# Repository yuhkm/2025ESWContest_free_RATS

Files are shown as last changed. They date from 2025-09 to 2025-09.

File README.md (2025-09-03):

# 2025ESWContest_free_RATS
<br/>

## Driving Assistance Device for Beginner Drivers

<p align="center">
 
</p>
<br/>

## System Overview
<p align="center">
 
</p>
<br/>

## Team Members
<div align="center">

| **안재원 (팀장)** | **김유환** | **박요한** | **박수현** | **정연홍** |
|:---:|:---:|:---:|:---:|:---:|
|  |  |  |  |  |
| [@JwAhn0830](https://github.com/JwAhn0830) | [@yuhkm](https://github.com/yuhkm) | [@doct-vg](https://github.com/doct-vg) | [@jstrfunctionk](https://github.com/strfunctionk) | [@zyh3569](https://github.com/zyh3569) |
| [Main Device (Gaze),](https://github.com/yuhkm/2025ESWContest_free_RATS/tree/main/Main_Device/gaze)<br/>[Server Communication](https://github.com/yuhkm/2025ESWContest_free_RATS/tree/main/Main_Device) | [Main Device (Lane),](https://github.com/yuhkm/2025ESWContest_free_RATS/tree/main/Main_Device/LDS)<br/>[HUD](https://github.com/yuhkm/2025ESWContest_free_RATS/tree/main/HUD) | [Vehicle Sensors,](https://github.com/yuhkm/2025ESWContest_free_RATS/tree/main/Main_Device/VDP)<br/>[CAD](https://github.com/yuhkm/2025ESWContest_free_RATS/tree/main/HW) | [Backend](https://github.com/yuhkm/2025ESWContest_free_RATS/tree/main/Backend) | [Frontend](https://github.com/yuhkm/2025ESWContest_free_RATS/tree/main/Frontend) |

</div>
<br/>

## Demo
- [YouTube](https://www.youtube.com/watch?v=WTc7l_RPrZw)  
<br/>

## Repo
- [Main Device](https://github.com/yuhkm/2025ESWContest_free_RATS/tree/main/Main_Device)  
- [HUD](https://github.com/yuhkm/2025ESWContest_free_RATS/tree/main/HUD)
- [Backend](https://github.com/yuhkm/2025ESWContest_free_RATS/tree/main/Backend)  
- [Frontend](https://github.com/yuhkm/2025ESWContest_free_RATS/tree/main/Frontend)  
- [HW](https://github.com/yuhkm/2025ESWContest_free_RATS/tree/main/HW)
<br/>

<br/>

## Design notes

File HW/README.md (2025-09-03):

# HW
- CAD
  - SolidWorks
- PCB
  - KiCAD  

<br>

## CAD

### Raspberry Pi 5 case  
  

### HUD case  
  

### Camera case  
  

### IMU case  
  

<br>
<br>

## PCB



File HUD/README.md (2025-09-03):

# HUD
<br>

This project receives **lane deviation** and **inter-vehicle distance** data from a Raspberry Pi, displays the information on an ESP32-based display module, and implements a **HUD** (Head-Up Display) using a combiner method.

<p align="center">
  
  
</p>

### Key Features
- Real-time visualization of lane deviation and following distance  
- Display output using ESP32 and LVGL  
- HUD implementation via combiner reflection  
- Touch-based UI with calibration functionality

<br>

## HW
- Waveshare ESP32-S3 2.41inch AMOLED Touch Display
  - MCU : ESP32-S3
  - Driver IC : RM690B0
  - Touch IC : FT6336

<br>

## SW
- **Squareline Studio** : 1.5.3
- **LVGL** : 8.3.11
- **IDE** : PlatformIO

<br>

## System Overview
<p align="center">
  
</p>
<br>

## HUD usage example

<table align="center">
  <tr>
    <td align="center">
      Offset calibration<br>
      <strong>Offset calibration mode</strong><br>
      <strong>&nbsp;</strong>
    </td>
    <td align="center">
      Left deviation<br>
      <strong>Center driving</strong><br>
      <strong>Safe distance</strong>
    </td>
  </tr>
  <tr>
    <td align="center">
      Normal driving<br>
      <strong>Left bias</strong><br>
      <strong>Warning distance</strong>
    </td>
    <td align="center">
      Normal driving<br>
      <strong>Right bias</strong><br>
      <strong>Dangerous distance</strong>
    </td>
  </tr>
</table>

<br>

## Project structure

```markdown
HUD
┣ HUD
┃ ┗ lib
┃ ┃ ┗ UI
┃ ┃   ┗ ...
┃ ┗ src
┃ ┃ ┣ esp_lcd_sh8601.c
┃ ┃ ┣ esp_lcd_sh8601.h
┃ ┃ ┣ esp_lcd_touch.c
┃ ┃ ┣ esp_lcd_touch.h
┃ ┃ ┣ esp_lcd_touch_ft5x06.c
┃ ┃ ┣ esp_lcd_touch_ft5x06.h
┃ ┃ ┣ hudCtrl.cpp
┃ ┃ ┣ hudCtrl.h
┃ ┃ ┗ main.cpp
┃ ┗ platformio.ini
┃
┣ libraries
┃ ┗ ESP32-audioI2S-master
┃ ┗ lvgl
┃ ┗ lv_conf.h
┃
┣ HUD_amoled_v1
┃ ┗ ...
┃
┗ README.md
```

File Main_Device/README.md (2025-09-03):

<p align="center">
   
</p>

# Dev Environemnt 
## Host Environment 
### Build PC 
- **CPU** : Intel i7 13th
- **GPU** : NVIDIA RTX 4050
- **RAM** : 32GB
- **OS** : Ubuntu-22.04 LTS (WSL2)
- **Target Hailo NPU** : Hailo8  

### Hailo SDK
- **Hailo Model Zoo** : 2.15v
- **DataFlow Compiler** : 3.31v
- **Hailort** : 4.21v
- **Python venv** : 3.10.2

## Target Environemnt
### HW
- **Target Board** : RasberryPI 5
- **NPU** : Hailo 8

### SW
- **Python** : 3.11.4
- **HailoRT** : 4.20v  

# System Overview
<p align="center">
 
</p>

- **MultiProcessor**
    - To enhance system efficiency and prevent resource bottlenecks, the application uses multiprocessing. Independent processes are assigned to handle gaze tracking (app.py) and lane detection with distance estimation (lds.py), enabling parallel execution of compute-intensive tasks.

- **MultiThread**
    - Multithreading is used for handling GPS and IMU data concurrently. GPS data is used to measure driving distance and speed, while IMU data helps determine the vehicle’s turn signal status (e.g., left or right turn). This approach improves responsiveness and stability of the system.

- **WebScoket**
  - the device and server are connected via a TCP-based websocket communication protocol.

- **Hailo NPU**
    - Since the Raspberry Pi lacks a dedicated GPU, the system utilizes the Hailo NPU for efficient and real-time AI model inference on edge device

- **Used  library**
    - *OpenCV* : For lane detection
    - *Mediapipe* : For estimating user's face angle 

- [HUD](https://github.com/Driving-Assistance-Device/HUD)
    - Lane deviation and inter-vehicle distance data are received from a Raspberry Pi and displayed on an ESP32 module. A combiner-type HUD then projects the information into the driver’s line of sight.

# multi-proess


- [main.py](https://github.com/Driving-Assistance-Device/Vehicle_Device/tree/main/DM)
    - Main process
    
- [lds.py](https://github.com/Driving-Assistance-Device/Vehicle_Device/tree/main/DM/LDS)
    - Lane & inter-vehicle distance detection system
- [gaze.py](https://github.com/Driving-Assistance-Device/Vehicle_Device/tree/main/DM/gaze)  
    - Gaze detection system

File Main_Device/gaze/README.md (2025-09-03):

## gaze.py



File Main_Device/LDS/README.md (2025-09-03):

## LDS.py


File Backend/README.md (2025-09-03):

<div align=center>
  
# Vehicle-BackEnd
초보 운전자를 위한 차량 보조 서비스 벡엔드 레포지토리 입니다.

## 인원

|  |
| :-----------------------------------------------------------------------------: |
|                    [박수현](https://github.com/strfunctionk)                    |

## 기술 스택

| 이름 | 소개 |
| --- | --- |
|  | \* 서버 사이드 JavaScript 환경입니다. |
|  | \* Node.js를 위한 웹 애플리케이션 프레임워크입니다. |
|  | \* 실시간 통신을 위한 웹소켓 라이브러리입니다. |
|  | _ EC2: 가상 서버 인스턴스를 제공하는 AWS 서비스입니다. <br> _ S3: 객체 스토리지 서비스입니다. <br> \* RDS: 관리형 관계형 데이터베이스 서비스입니다. |
|  | \* 관계형 데이터베이스 서비스입니다. |
|  | \* ORM(Object-Relational Mapping) 라이브러리입니다. |

</div>

## 개요

- 명칭 : Vehicle
- 개발인원 : 1명 (박수현)
- 개발기간 : 2025.06.24 ~ ing
- 브랜치전략 : GitHub-Flow

## 코딩 컨벤션

- **변수, 함수:** 카멜케이스 (예: `userName`)
- **매개변수:** 스네이크케이스 (예: `user_name`)

## Commit

- `feature` : 새로운 기능이 추가되는 경우
- `fix` : bug가 수정되는 경우
- `docs` : 문서에 변경 사항이 있는 경우
- `refactor` : 코드 리팩토링하는 경우 (기능 변경 없이 구조 개선)

## PR 템플릿

```markdown
#️⃣연관된 이슈

ex) #이슈번호, #이슈번호

📝작업 내용
이번 PR에서 작업한 내용을 간략히 설명해주세요(이미지 첨부 가능)

스크린샷 (선택)

💬리뷰 요구사항(선택)
```

## 프로젝트 구조

```markdown
📦 project/
┃ 📂prisma/
┃ ┗ 📜schema.prisma
┣ 📂src/
┃ ┣ 📂routes/
┃ ┃ ┗ 📜index.js
┃ ┃ ┗ 📜auth.services.js
┃ ┃ ┗ 📜driving.services.js
┃ ┃ ┗ 📜user.services.js
┃ ┣ 📂controllers/
┃ ┃ ┗ 📜auth.controller.js
┃ ┃ ┗ 📜driving.controller.js
┃ ┃ ┗ 📜user.controller.js
┃ ┣ 📂dtos/
┃ ┃ ┗ 📜auth.dto.js
┃ ┃ ┗ 📜device.dto.js
┃ ┃ ┗ 📜driving.dto.js
┃ ┃ ┗ 📜user.dto.js
┃ ┣ 📂services/
┃ ┃ ┗ 📜auth.services.js
┃ ┃ ┗ 📜device.services.js
┃ ┃ ┗ 📜driving.services.js
┃ ┃ ┗ 📜user.services.js
┃ ┣ 📂repositories/
┃ ┃ ┗ 📜auth.repository.js
┃ ┃ ┗ 📜device.repository.js
┃ ┃ ┗ 📜driving.repository.js
┃ ┃ ┗ 📜user.repository.js
┃ ┣ 📂middlewares/
┃ ┃ ┗ 📜auth.middleware.js
┃ ┣ 📂utils/
┃ ┃ ┗ 📜crypto.util.js
┃ ┃ ┗ 📜jwt.util.js
┃ ┣ 📂errors/
┃ ┃ ┣ 📜auth.errors.js
┃ ┃ ┣ 📜device.errors.js
┃ ┃ ┣ 📜driving.errors.js
┃ ┃ ┣ 📜user.errors.js
┃ ┣ 📂db/
┃ ┃ ┣ 📜db.config.js
┃ ┗ 📜index.js
┃ 📂test/
┃ ┗ 📜socket.test.js
┣ 📜.env
┗ 📜README.md
```

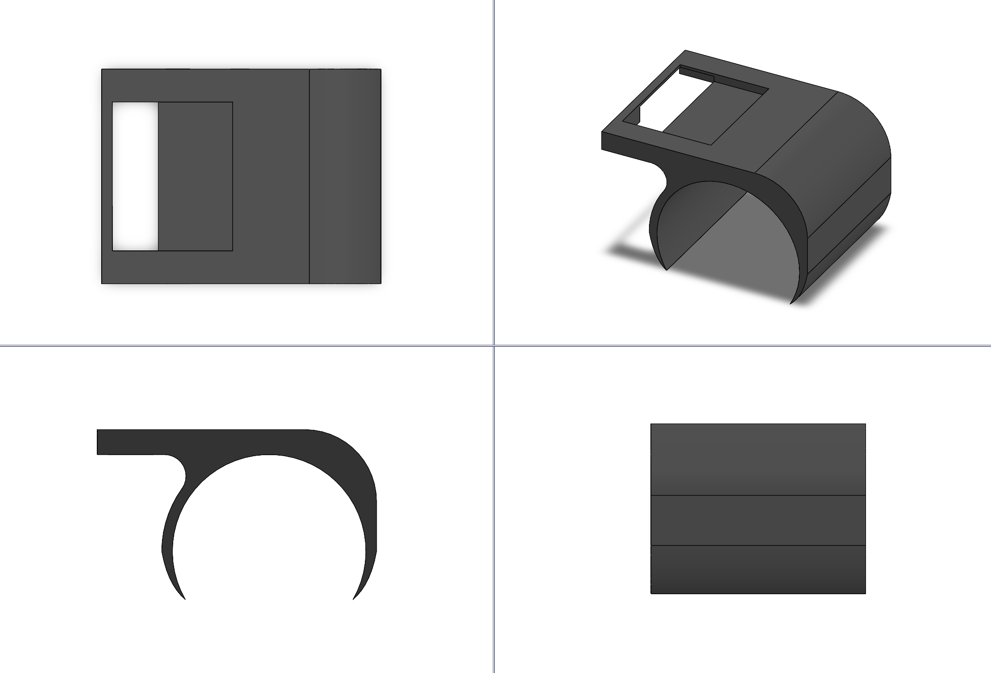
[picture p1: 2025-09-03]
HW/cad/IMU/IMU_case_img.png

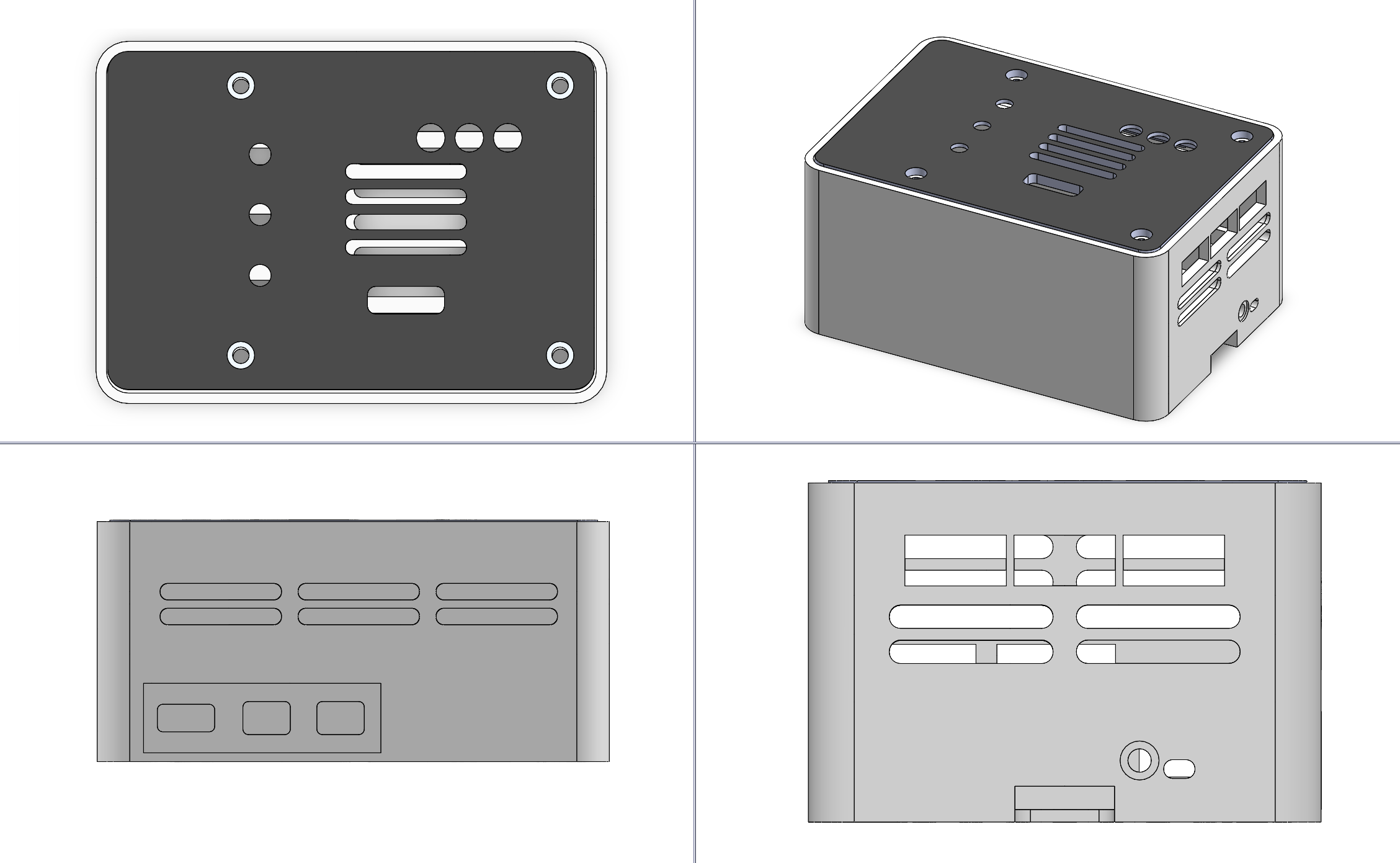
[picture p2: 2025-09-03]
HW/cad/Raspberry Pi5/RP5_case_img.png

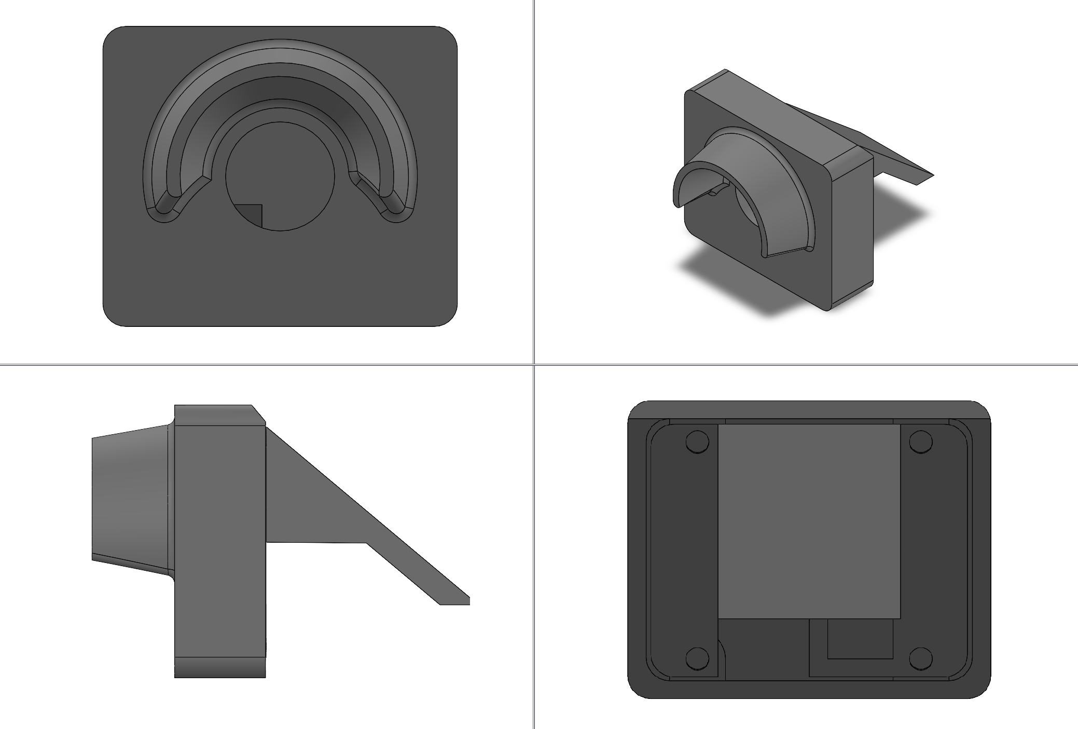
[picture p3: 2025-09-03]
HW/cad/Cam/cam_case_img.png

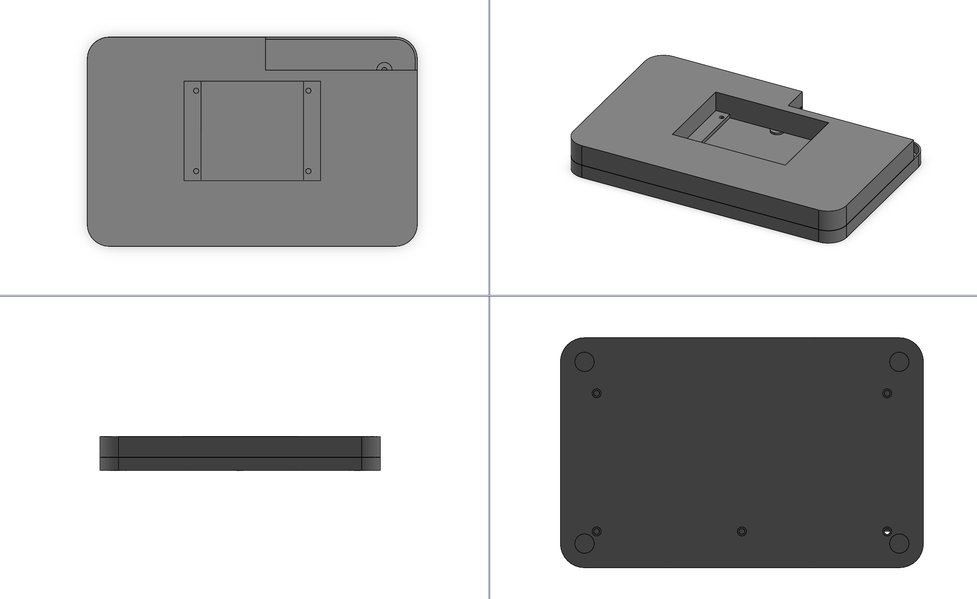
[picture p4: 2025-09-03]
HW/cad/HUD/HUD_case_img.png

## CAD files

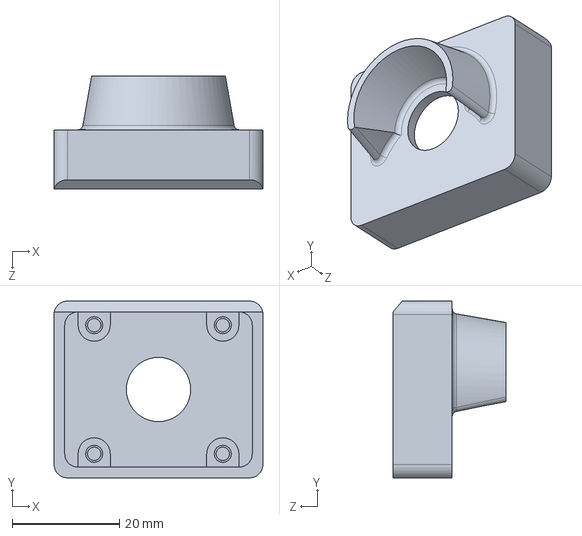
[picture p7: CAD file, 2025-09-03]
HW/cad/Cam/camCase_t.SLDPRT
39.0 x 33.0 x 21.0 mm

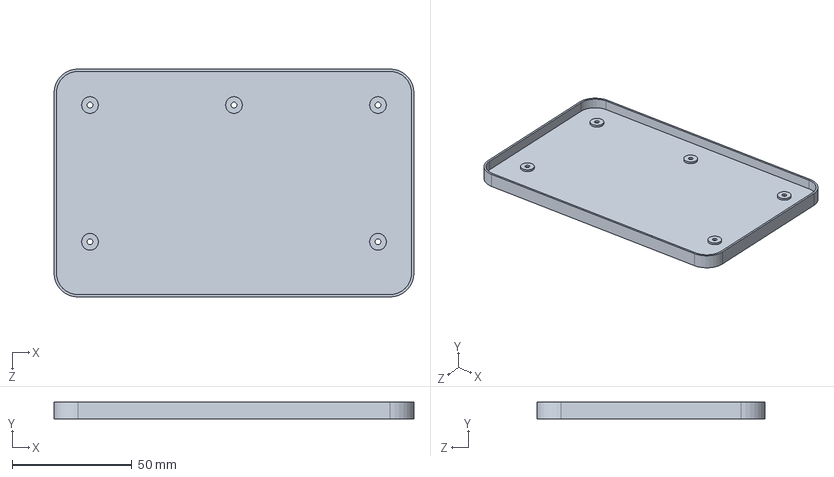
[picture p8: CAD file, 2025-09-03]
HW/cad/HUD/hud_btm.SLDPRT
150.0 x 7.00 x 95.0 mm

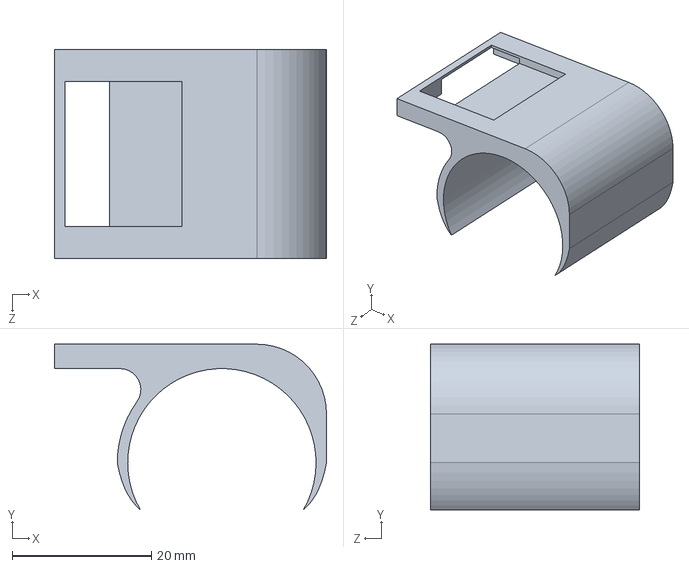
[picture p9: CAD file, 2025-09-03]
HW/cad/IMU/IMU_case.SLDPRT
39.0 x 23.8 x 30.0 mm

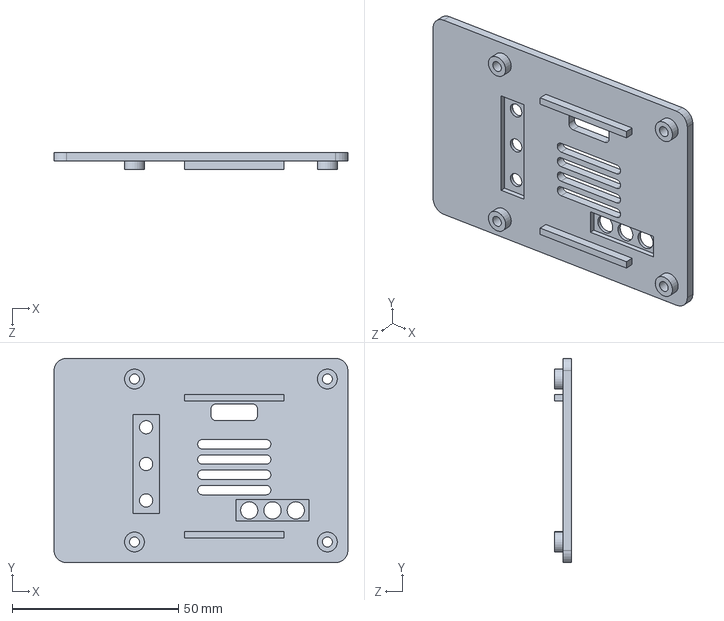
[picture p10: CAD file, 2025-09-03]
HW/cad/Raspberry Pi5/pi5_top.SLDPRT
88.4 x 61.4 x 5.00 mm

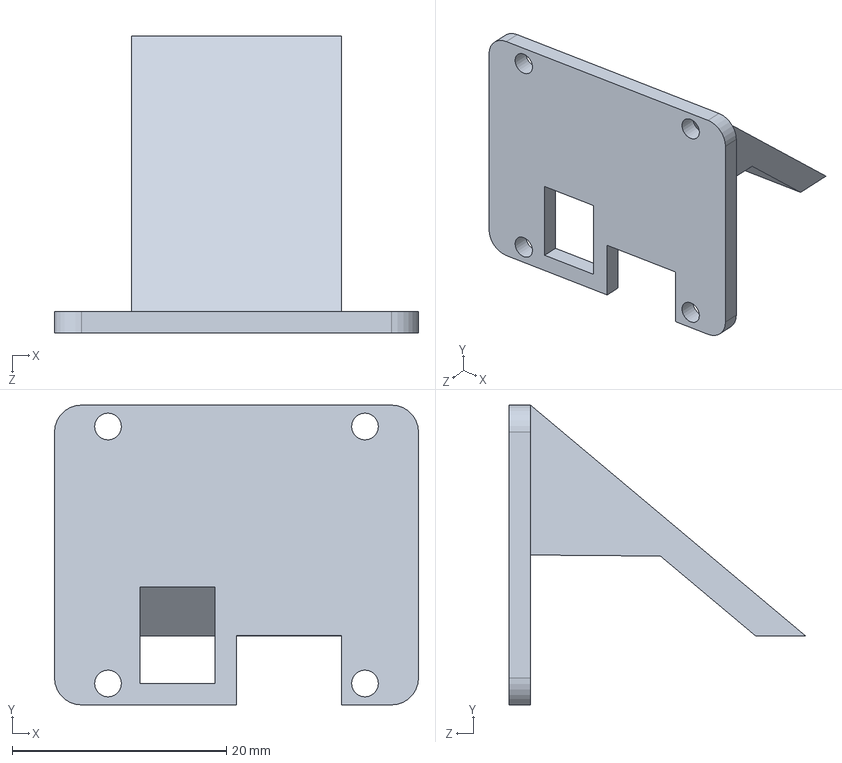
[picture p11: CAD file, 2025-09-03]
HW/cad/Cam/camCase_b.SLDPRT
34.0 x 28.0 x 27.7 mm

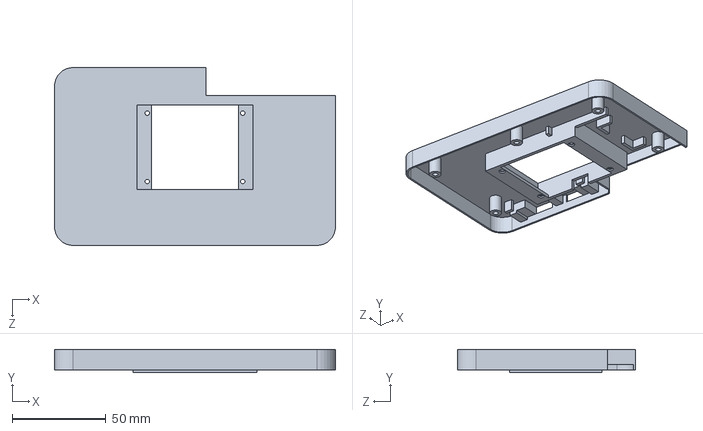
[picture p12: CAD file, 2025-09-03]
HW/cad/HUD/hud_top.SLDPRT
150.0 x 12.5 x 95.0 mm

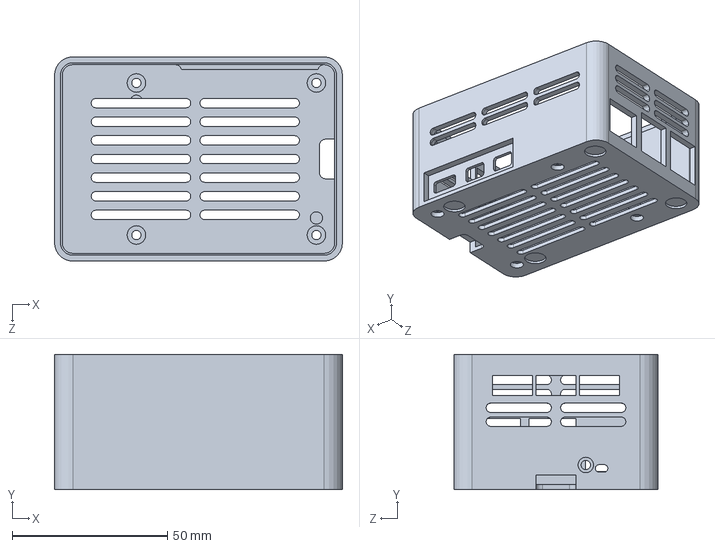
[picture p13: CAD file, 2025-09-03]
HW/cad/Raspberry Pi5/pi5_case.SLDPRT
92.8 x 43.5 x 65.8 mm

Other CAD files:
HW/cad/Cam/camCase_b.STL
HW/cad/Cam/camCase_t.STL
HW/cad/HUD/hud_btm.STL
HW/cad/HUD/hud_top.STL
HW/cad/IMU/IMU_case.STL
HW/cad/Raspberry Pi5/pi5_case.STL
HW/cad/Raspberry Pi5/pi5_top.STL

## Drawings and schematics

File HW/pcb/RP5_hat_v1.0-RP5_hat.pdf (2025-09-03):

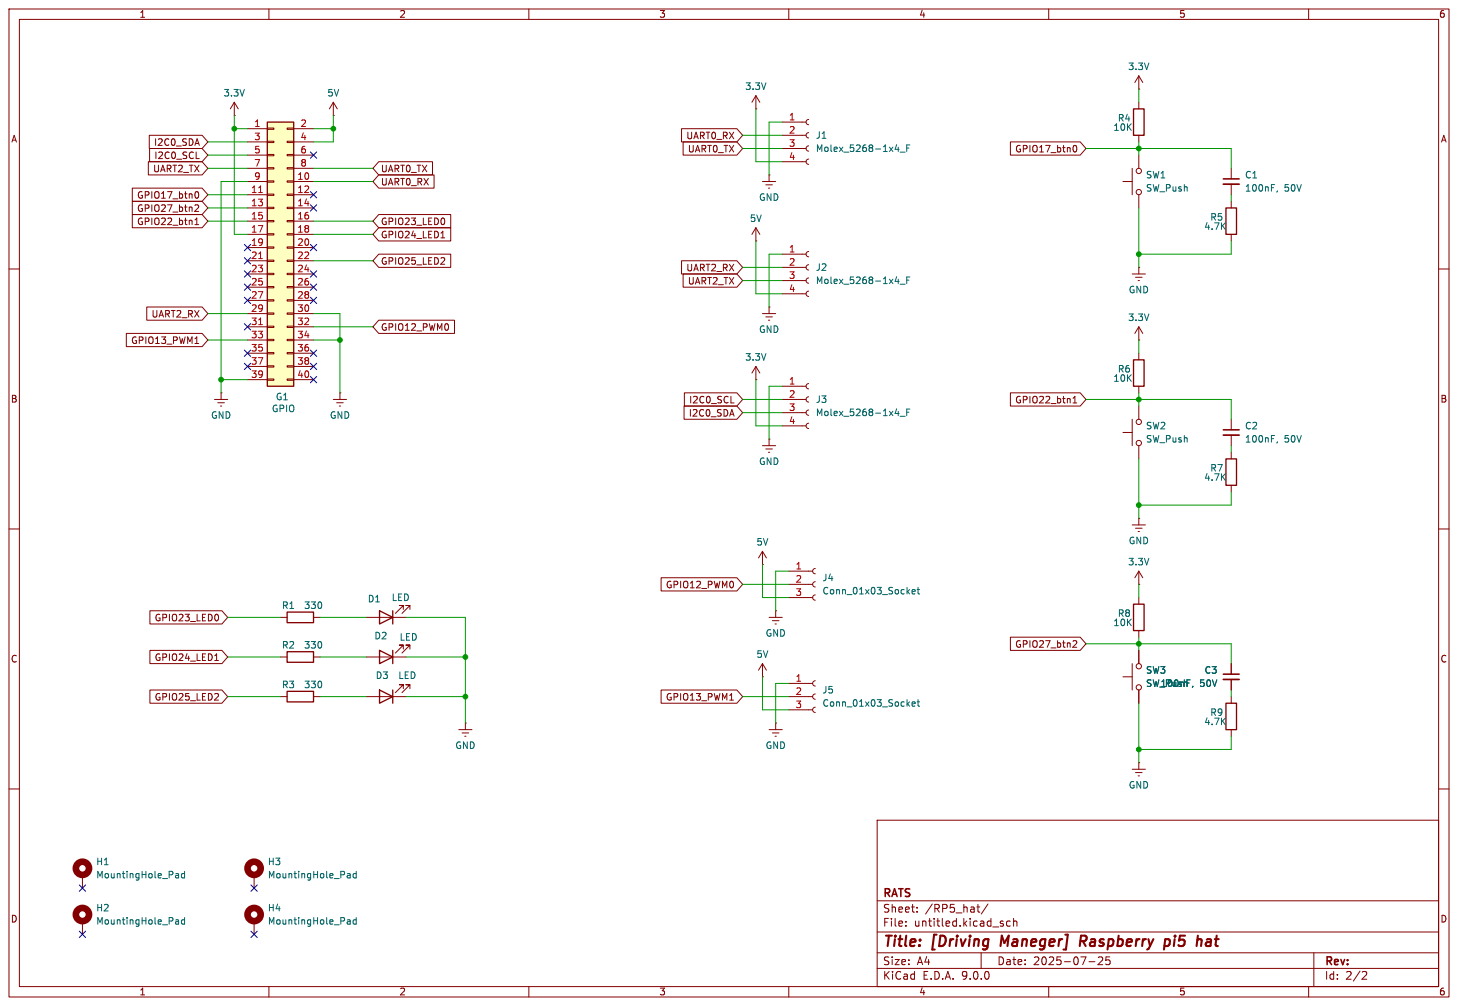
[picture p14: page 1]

Id: 2/2 Title: [Driving Maneger] Raspberry pi5 hat File: untitled.kicad_sch Sheet: /RP5_hat/ RATS

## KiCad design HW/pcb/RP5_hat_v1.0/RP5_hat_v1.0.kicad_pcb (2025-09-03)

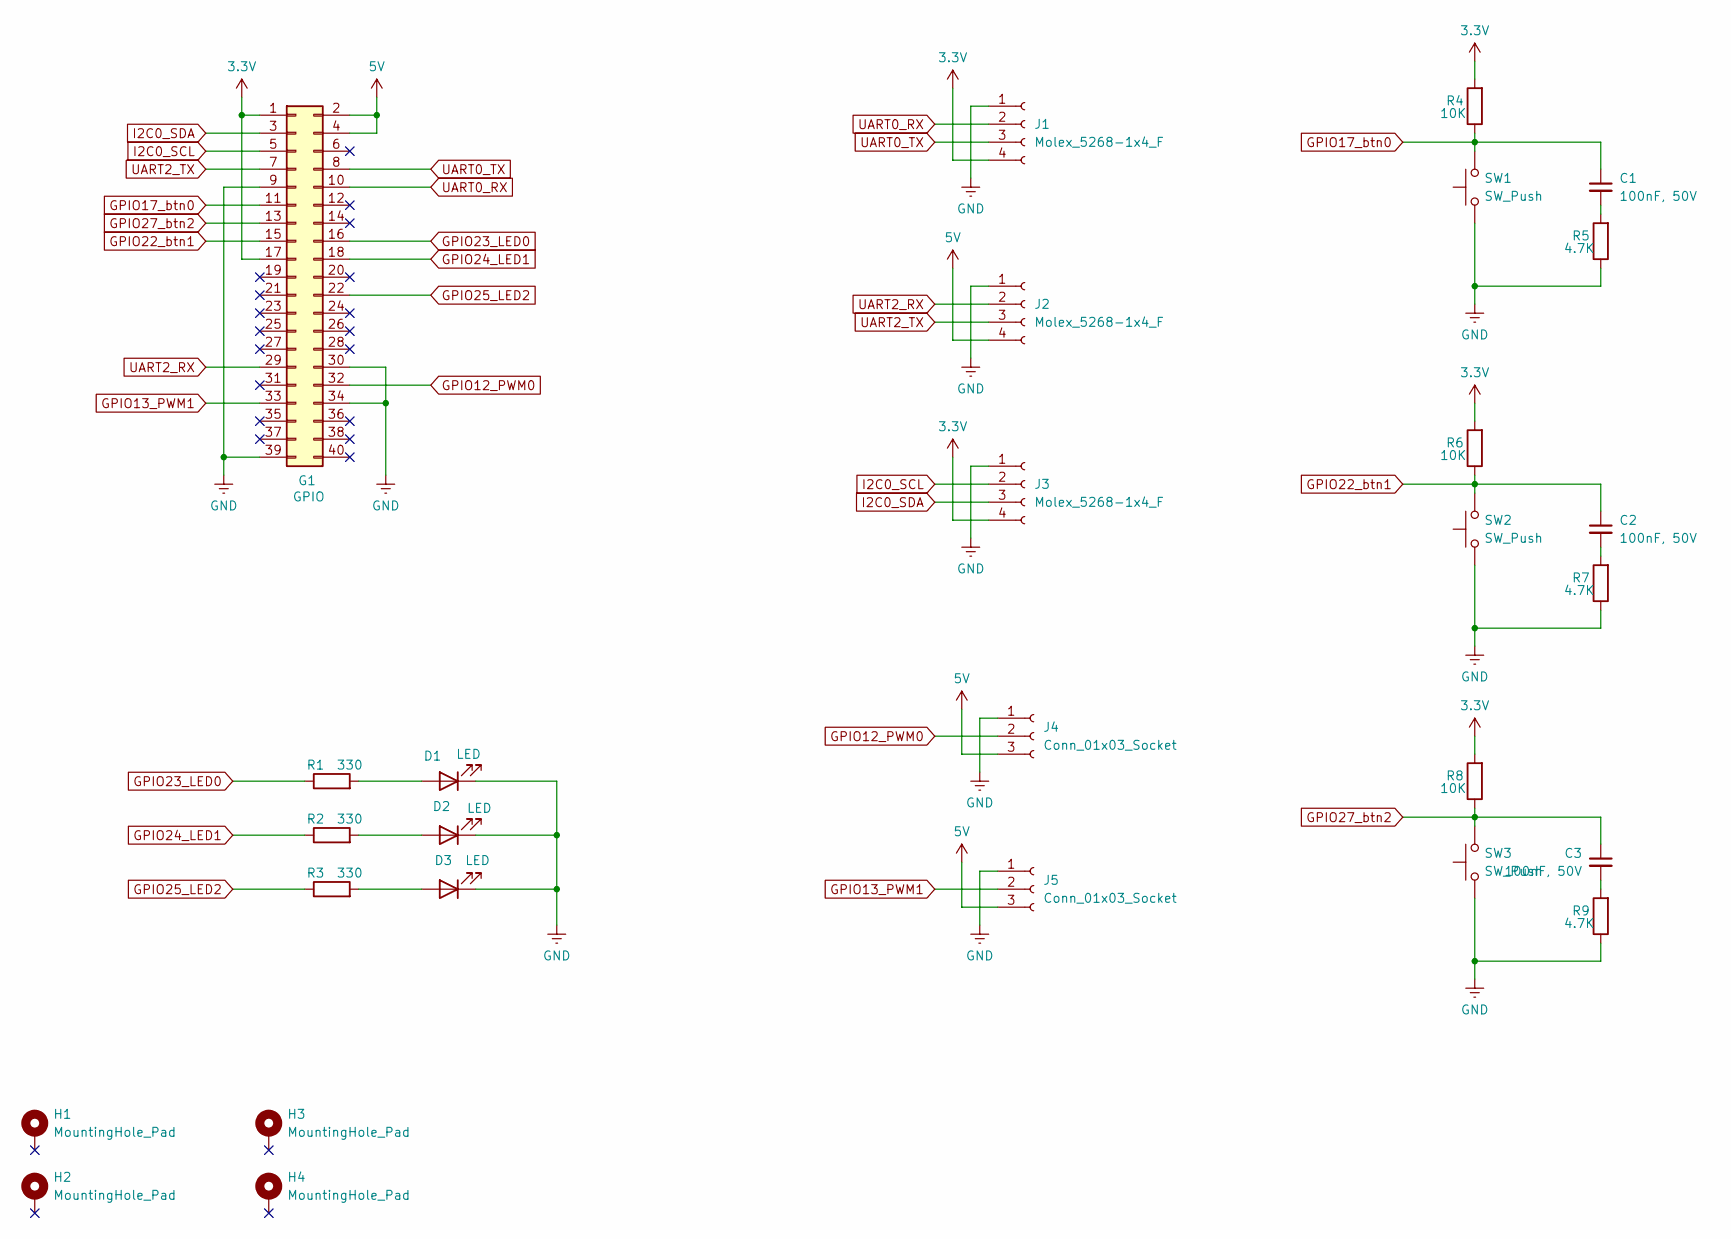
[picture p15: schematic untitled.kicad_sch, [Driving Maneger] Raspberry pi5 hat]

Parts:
C1, C2, C3: 100nF, 50V; CP_Radial_D5.0mm_P2.50mm
D1, D2, D3: LED; LED_D3.0mm
G1: GPIO; PinHeader_2x20_P2.54mm_Vertical
H1, H2, H3, H4: MountingHole_Pad; MountingHole_2.7mm_M2.5_DIN965_Pad_TopBottom
J1, J2, J3: Molex_5268-1x4_F; Molex_SPOX_5267-04A_1x04_P2.50mm_Vertical
J4, J5: Conn_01x03_Socket; Molex_SPOX_5267-03A_1x03_P2.50mm_Vertical
R1, R2, R3: 330; R_Axial_DIN0204_L3.6mm_D1.6mm_P7.62mm_Horizontal
R4, R6, R8: 10K; R_Axial_DIN0204_L3.6mm_D1.6mm_P7.62mm_Horizontal
R5, R7, R9: 4.7K; R_Axial_DIN0204_L3.6mm_D1.6mm_P7.62mm_Horizontal
SW1, SW2, SW3: SW_Push; SW_PUSH_6mm

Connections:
3.3V: G1.1, G1.17, J1.4, J3.4, R4.2, R6.2, R8.2
5V: G1.2, G1.4, J2.4, J4.3, J5.3
GND: D1.1 (K), D2.1 (K), D3.1 (K), G1.9, G1.30, G1.34, G1.39, J1.1, J2.1, J3.1, J4.1, J5.1, R5.1, R7.1, R9.1, SW1.1, SW2.1, SW3.1
GPIO12_PWM0: G1.32, J4.2
GPIO13_PWM1: G1.33, J5.2
GPIO17_btn0: C1.1, G1.11, R4.1, SW1.2
GPIO22_btn1: C2.1, G1.15, R6.1, SW2.2
GPIO23_LED0: G1.16, R1.1
GPIO24_LED1: G1.18, R2.1
GPIO25_LED2: G1.22, R3.1
GPIO27_btn2: C3.1, G1.13, R8.1, SW3.2
I2C0_SCL: G1.5, J3.2
I2C0_SDA: G1.3, J3.3
unnamed: C1.2, R5.2
unnamed: C2.2, R7.2
unnamed: C3.2, R9.2
unnamed: D1.2 (A), R1.2
unnamed: D2.2 (A), R2.2
unnamed: D3.2 (A), R3.2
UART0_RX: G1.10, J1.2
UART0_TX: G1.8, J1.3
UART2_RX: G1.29, J2.2
UART2_TX: G1.7, J2.3

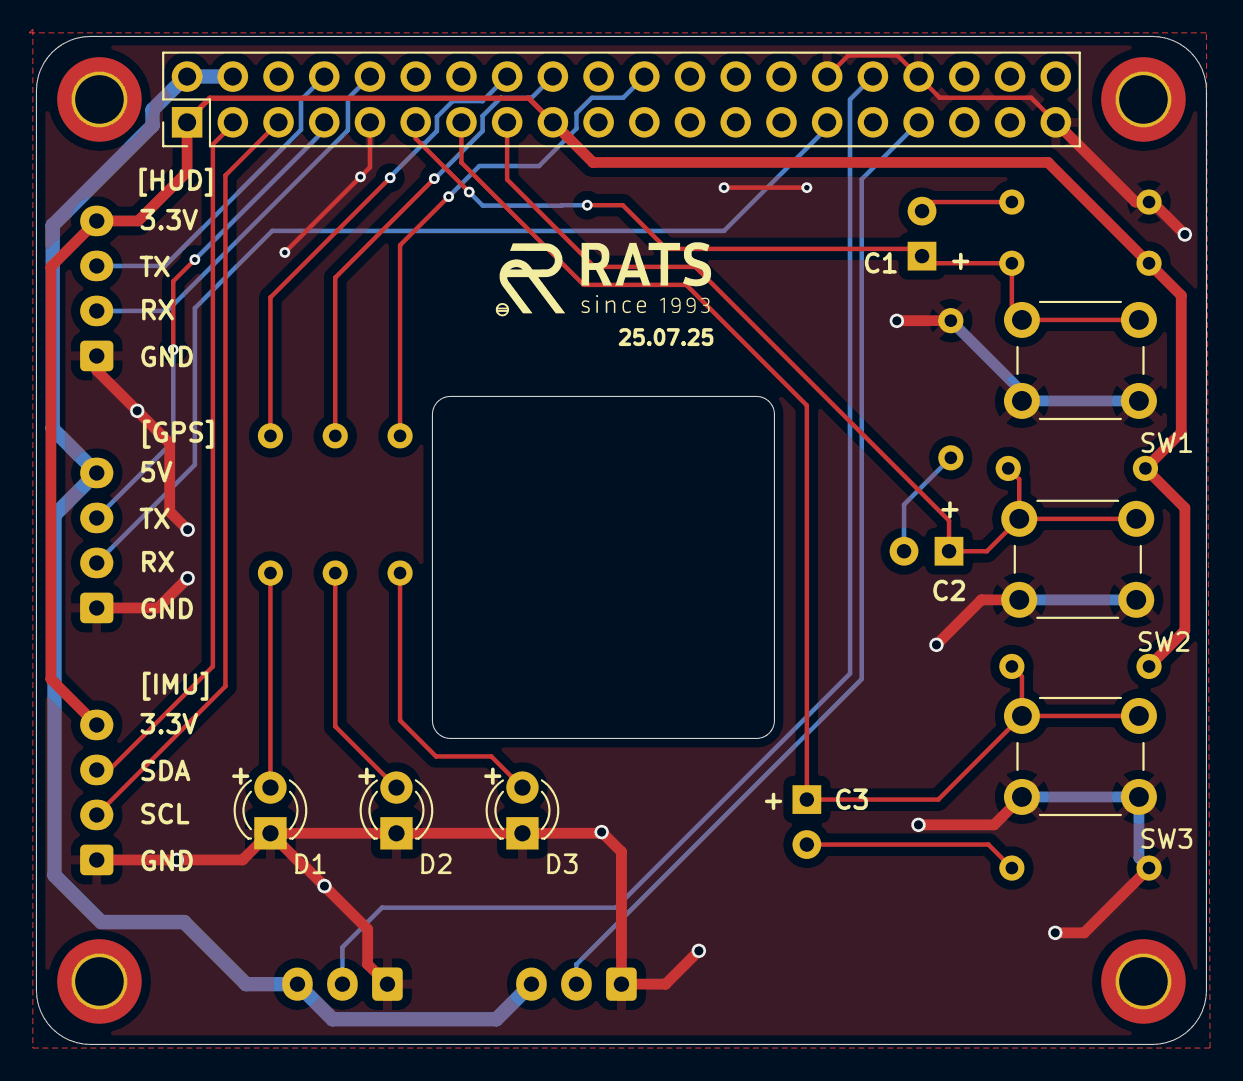
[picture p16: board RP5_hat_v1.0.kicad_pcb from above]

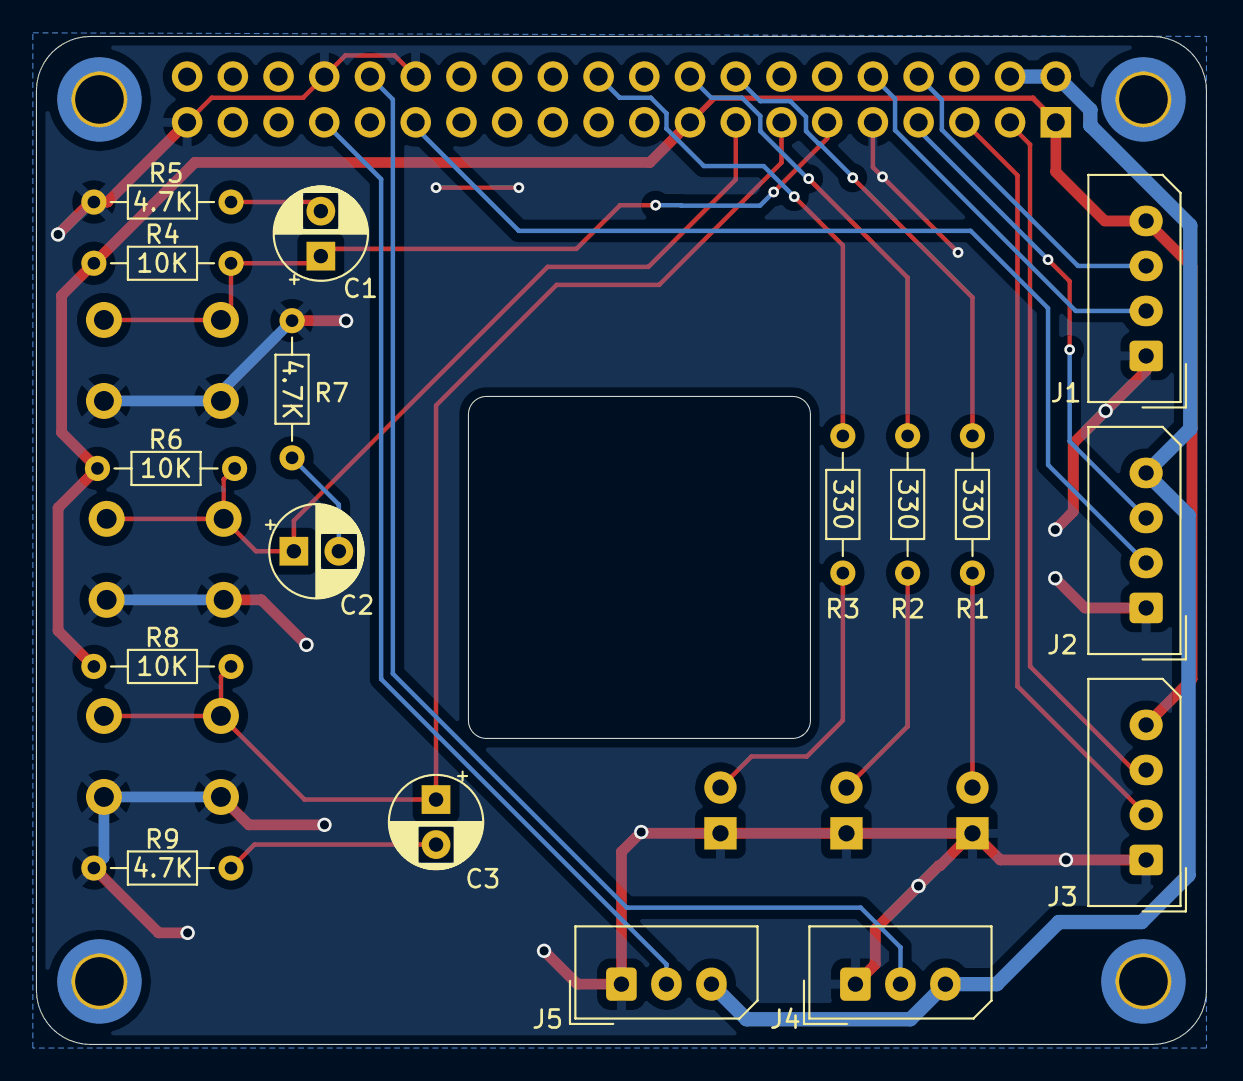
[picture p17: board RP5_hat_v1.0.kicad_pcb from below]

Board: 2 copper layers, 65.0 x 56.0 mm, 28 parts (17 on the bottom side), 23 nets.

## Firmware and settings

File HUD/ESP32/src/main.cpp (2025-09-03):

#include <Arduino.h>

#include <stdio.h>
#include <lvgl.h>

#include "freertos/FreeRTOS.h"
#include "freertos/task.h"
#include "driver/gpio.h"
#include "driver/i2c.h"
#include "driver/spi_master.h"
#include "esp_timer.h"
#include "esp_lcd_panel_io.h"
#include "esp_lcd_panel_vendor.h"
#include "esp_lcd_panel_ops.h"
#include "esp_err.h"
#include "esp_log.h"

#include "esp_lcd_sh8601.h"
#include "esp_lcd_touch_ft5x06.h"


#include <ui.h>

#include "hudCtrl.h"
#include "nvs_flash.h"
#include "nvs.h"


#define Rotate_90      0
#define Rotate_NONO    1

#define AMOLED_Rotate  Rotate_90

static const char *TAG = "example";
static SemaphoreHandle_t lvgl_mux = NULL;

#define LCD_HOST    SPI2_HOST
#define TOUCH_HOST  I2C_NUM_0


#define LCD_BIT_PER_PIXEL       (16)

#define EXAMPLE_LCD_BK_LIGHT_ON_LEVEL  1
#define EXAMPLE_LCD_BK_LIGHT_OFF_LEVEL !EXAMPLE_LCD_BK_LIGHT_ON_LEVEL
#define EXAMPLE_PIN_NUM_LCD_CS            (GPIO_NUM_9)
#define EXAMPLE_PIN_NUM_LCD_PCLK          (GPIO_NUM_10) 
#define EXAMPLE_PIN_NUM_LCD_DATA0         (GPIO_NUM_11)
#define EXAMPLE_PIN_NUM_LCD_DATA1         (GPIO_NUM_12)
#define EXAMPLE_PIN_NUM_LCD_DATA2         (GPIO_NUM_13)
#define EXAMPLE_PIN_NUM_LCD_DATA3         (GPIO_NUM_14)
#define EXAMPLE_PIN_NUM_LCD_RST           (GPIO_NUM_21)
#define EXAMPLE_PIN_NUM_BK_LIGHT          (-1)

// The pixel number in horizontal and vertical
#if (AMOLED_Rotate == Rotate_90)
#define EXAMPLE_LCD_H_RES              600    
#define EXAMPLE_LCD_V_RES              450
#else
#define EXAMPLE_LCD_H_RES              450  
#define EXAMPLE_LCD_V_RES              600
#endif

#define EXAMPLE_USE_TOUCH              1 //Without tp ---- Touch off

#if EXAMPLE_USE_TOUCH
#define EXAMPLE_PIN_NUM_TOUCH_SCL         (GPIO_NUM_48)
#define EXAMPLE_PIN_NUM_TOUCH_SDA         (GPIO_NUM_47)
#define EXAMPLE_PIN_NUM_TOUCH_RST         (gpio_num_t)(-1)
#define EXAMPLE_PIN_NUM_TOUCH_INT         (gpio_num_t)(-1)

esp_lcd_touch_handle_t tp = NULL;
#endif

#define EXAMPLE_LVGL_BUF_HEIGHT        (EXAMPLE_LCD_V_RES/10)
#define EXAMPLE_LVGL_TICK_PERIOD_MS    2
#define EXAMPLE_LVGL_TASK_MAX_DELAY_MS 500
#define EXAMPLE_LVGL_TASK_MIN_DELAY_MS 1
#define EXAMPLE_LVGL_TASK_STACK_SIZE   (4 * 1024)
#define EXAMPLE_LVGL_TASK_PRIORITY     2

static const sh8601_lcd_init_cmd_t lcd_init_cmds[] = {

  {0xFE, (uint8_t []){0x20}, 1, 0},	
  {0x26, (uint8_t []){0x0A}, 1, 0}, 
  {0x24, (uint8_t []){0x80}, 1, 0}, 

  {0xFE, (uint8_t []){0x00}, 1, 0},    
  {0x3A, (uint8_t []){0x55}, 1, 0},      
  {0xC2, (uint8_t []){0x00}, 1, 10},  
  {0x35, (uint8_t []){0x00}, 0, 0}, 
  {0x51, (uint8_t []){0x00}, 1, 10},
  {0x11, (uint8_t []){0x00}, 0, 80},  
  {0x2A, (uint8_t []){0x00,0x10,0x01,0xD1}, 4, 0},
  {0x2B, (uint8_t []){0x00,0x00,0x02,0x57}, 4, 0},
  // {0x30, (uint8_t []){0x00, 0x01,0x02, 0x56}, 4, 0},   
  {0x29, (uint8_t []){0x00}, 0, 10},
#if (AMOLED_Rotate == Rotate_90)
  {0x36, (uint8_t []){0x30}, 1, 0},     
#endif
  {0x51, (uint8_t []){0xFF}, 1, 0},//Write Display Brightness MAX_VAL=0XFF

};
static bool example_notify_lvgl_flush_ready(esp_lcd_panel_io_handle_t panel_io, esp_lcd_panel_io_event_data_t *edata, void *user_ctx)
{
  lv_disp_drv_t *disp_driver = (lv_disp_drv_t *)user_ctx;
  lv_disp_flush_ready(disp_driver);
  return false;
}
static void example_lvgl_flush_cb(lv_disp_drv_t *drv, const lv_area_t *area, lv_color_t *color_map)
{
  esp_lcd_panel_handle_t panel_handle = (esp_lcd_panel_handle_t) drv->user_data;
#if (AMOLED_Rotate == Rotate_90)
  const int offsetx1 = area->x1;
  const int offsetx2 = area->x2;
  const int offsety1 = area->y1 + 16;
  const int offsety2 = area->y2 + 16;
#else
  const int offsetx1 = area->x1 + 16;
  const int offsetx2 = area->x2 + 16;
  const int offsety1 = area->y1;
  const int offsety2 = area->y2;
#endif
  // copy a buffer's content to a specific area of the display
  esp_lcd_panel_draw_bitmap(panel_handle, offsetx1, offsety1, offsetx2 + 1, offsety2 + 1, color_map);
}
/* Rotate display and touch, when rotated screen in LVGL. Called when driver parameters are updated. */
static void example_lvgl_update_cb(lv_disp_drv_t *drv)
{
  esp_lcd_panel_handle_t panel_handle = (esp_lcd_panel_handle_t) drv->user_data;

  switch (drv->rotated)
  {
    case LV_DISP_ROT_NONE:
      // Rotate LCD display
      esp_lcd_panel_swap_xy(panel_handle, false);
      esp_lcd_panel_mirror(panel_handle, true, false);
      break;
    case LV_DISP_ROT_90:
      // Rotate LCD display
      esp_lcd_panel_swap_xy(panel_handle, true);
      esp_lcd_panel_mirror(panel_handle, true, true);
      break;
    case LV_DISP_ROT_180:
      // Rotate LCD display
      esp_lcd_panel_swap_xy(panel_handle, false);
      esp_lcd_panel_mirror(panel_handle, false, true);
      break;
    case LV_DISP_ROT_270:
      // Rotate LCD display
      esp_lcd_panel_swap_xy(panel_handle, true);
      esp_lcd_panel_mirror(panel_handle, false, false);
      break;
  }
}
void example_lvgl_rounder_cb(struct _lv_disp_drv_t *disp_drv, lv_area_t *area)
{
  uint16_t x1 = area->x1;
  uint16_t x2 = area->x2;

  uint16_t y1 = area->y1;
  uint16_t y2 = area->y2;

  // round the start of coordinate down to the nearest 2M number
  area->x1 = (x1 >> 1) << 1;
  area->y1 = (y1 >> 1) << 1;
  // round the end of coordinate up to the nearest 2N+1 number
  area->x2 = ((x2 >> 1) << 1) + 1;
  area->y2 = ((y2 >> 1) << 1) + 1;
}

#if EXAMPLE_USE_TOUCH
static void example_lvgl_touch_cb(lv_indev_drv_t *drv, lv_indev_data_t *data)
{
    esp_lcd_touch_handle_t tp = (esp_lcd_touch_handle_t)drv->user_data;
    assert(tp);

    uint16_t tp_x;
    uint16_t tp_y;
    uint8_t tp_cnt = 0;
    /* Read data from touch controller into memory */
    esp_lcd_touch_read_data(tp);
    /* Read data from touch controller */
    bool tp_pressed = esp_lcd_touch_get_coordinates(tp, &tp_x, &tp_y, NULL, &tp_cnt, 1);
    if (tp_pressed && tp_cnt > 0) {
        data->point.x = tp_x ;
        data->point.y = tp_y ;
        data->state = LV_INDEV_STATE_PRESSED;
        ESP_LOGD(TAG, "Touch position: %d,%d", tp_x, tp_y);
    } else {
        data->state = LV_INDEV_STATE_RELEASED;
    }
}
#endif

static void example_increase_lvgl_tick(void *arg)
{
  /* Tell LVGL how many milliseconds has elapsed */
  lv_tick_inc(EXAMPLE_LVGL_TICK_PERIOD_MS);
}
static bool example_lvgl_lock(int timeout_ms)
{
  assert(lvgl_mux && "bsp_display_start must be called first");

  const TickType_t timeout_ticks = (timeout_ms == -1) ? portMAX_DELAY : pdMS_TO_TICKS(timeout_ms);
  return xSemaphoreTake(lvgl_mux, timeout_ticks) == pdTRUE;
}
static void example_lvgl_unlock(void)
{
  assert(lvgl_mux && "bsp_display_start must be called first");
  xSemaphoreGive(lvgl_mux);
}
static void example_lvgl_port_task(void *arg)
{
  ESP_LOGI(TAG, "Starting LVGL task");
  uint32_t task_delay_ms = EXAMPLE_LVGL_TASK_MAX_DELAY_MS;
  while (1)
  {
    // Lock the mutex due to the LVGL APIs are not thread-safe
    if (example_lvgl_lock(-1)) {
        task_delay_ms = lv_timer_handler();
        // Release the mutex
        example_lvgl_unlock();
    }
    if (task_delay_ms > EXAMPLE_LVGL_TASK_MAX_DELAY_MS) {
        task_delay_ms = EXAMPLE_LVGL_TASK_MAX_DELAY_MS;
    } else if (task_delay_ms < EXAMPLE_LVGL_TASK_MIN_DELAY_MS) {
        task_delay_ms = EXAMPLE_LVGL_TASK_MIN_DELAY_MS;
    }
    vTaskDelay(pdMS_TO_TICKS(task_delay_ms));
  }
}



void setup()
{
  static lv_disp_draw_buf_t disp_buf; // contains internal graphic buffer(s) called draw buffer(s)
  static lv_disp_drv_t disp_drv;      // contains callback functions
#if EXAMPLE_PIN_NUM_BK_LIGHT >= 0
    ESP_LOGI(TAG, "Turn off LCD backlight");
    gpio_config_t bk_gpio_config = {
        .pin_bit_mask = 1ULL << EXAMPLE_PIN_NUM_BK_LIGHT,
        .mode = GPIO_MODE_OUTPUT,
    };
    ESP_ERROR_CHECK(gpio_config(&bk_gpio_config));
#endif
  ESP_LOGI(TAG, "Initialize SPI bus");
  const spi_bus_config_t buscfg = SH8601_PANEL_BUS_QSPI_CONFIG(EXAMPLE_PIN_NUM_LCD_PCLK,
                                                               EXAMPLE_PIN_NUM_LCD_DATA0,
                                                               EXAMPLE_PIN_NUM_LCD_DATA1,
                                                               EXAMPLE_PIN_NUM_LCD_DATA2,
                                                               EXAMPLE_PIN_NUM_LCD_DATA3,
                                                               EXAMPLE_LCD_H_RES * EXAMPLE_LCD_V_RES * LCD_BIT_PER_PIXEL / 8);
  ESP_ERROR_CHECK(spi_bus_initialize(LCD_HOST, &buscfg, SPI_DMA_CH_AUTO));

  ESP_LOGI(TAG, "Install panel IO");
  esp_lcd_panel_io_handle_t io_handle = NULL;
  const esp_lcd_panel_io_spi_config_t io_config = SH8601_PANEL_IO_QSPI_CONFIG(EXAMPLE_PIN_NUM_LCD_CS,
                                                                                example_notify_lvgl_flush_ready,
                                                                                &disp_drv);
  sh8601_vendor_config_t vendor_config = {
      .init_cmds = lcd_init_cmds,
      .init_cmds_size = sizeof(lcd_init_cmds) / sizeof(lcd_init_cmds[0]),
      .flags = {
          .use_qspi_interface = 1,
      },
  };
    // Attach the LCD to the SPI bus
  ESP_ERROR_CHECK(esp_lcd_new_panel_io_spi((esp_lcd_spi_bus_handle_t)LCD_HOST, &io_config, &io_handle));

  esp_lcd_panel_handle_t panel_handle = NULL;
  const esp_lcd_panel_dev_config_t panel_config = {
      .reset_gpio_num = EXAMPLE_PIN_NUM_LCD_RST,
      .rgb_ele_order = LCD_RGB_ELEMENT_ORDER_RGB,
      .bits_per_pixel = LCD_BIT_PER_PIXEL,
      .vendor_config = &vendor_config,
  };
  ESP_LOGI(TAG, "Install SH8601 panel driver");
  ESP_ERROR_CHECK(esp_lcd_new_panel_sh8601(io_handle, &panel_config, &panel_handle));
  ESP_ERROR_CHECK(esp_lcd_panel_reset(panel_handle));
  ESP_ERROR_CHECK(esp_lcd_panel_init(panel_handle));
  // user can flush pre-defined pattern to the screen before we turn on the screen or backlight
  ESP_ERROR_CHECK(esp_lcd_panel_disp_on_off(panel_handle, true));
#if EXAMPLE_USE_TOUCH
    ESP_LOGI(TAG, "Initialize I2C bus");
    const i2c_config_t i2c_conf = 
    {
        .mode = I2C_MODE_MASTER,
        .sda_io_num = EXAMPLE_PIN_NUM_TOUCH_SDA,
        .scl_io_num = EXAMPLE_PIN_NUM_TOUCH_SCL,
        .sda_pullup_en = GPIO_PULLUP_ENABLE,
        .scl_pullup_en = GPIO_PULLUP_ENABLE,
        .master = {.clk_speed = 300 * 1000,},
    };
    ESP_ERROR_CHECK(i2c_param_config(TOUCH_HOST, &i2c_conf));
    ESP_ERROR_CHECK(i2c_driver_install(TOUCH_HOST, i2c_conf.mode, 0, 0, 0));
    
    esp_lcd_panel_io_handle_t tp_io_handle = NULL;
    const esp_lcd_panel_io_i2c_config_t tp_io_config = ESP_LCD_TOUCH_IO_I2C_FT5x06_CONFIG();
    // Attach the TOUCH to the I2C bus
    ESP_ERROR_CHECK(esp_lcd_new_panel_io_i2c((esp_lcd_i2c_bus_handle_t)TOUCH_HOST, &tp_io_config, &tp_io_handle));

    const esp_lcd_touch_config_t tp_cfg = {
        .x_max = EXAMPLE_LCD_V_RES-1,
        .y_max = EXAMPLE_LCD_H_RES-1,
        .rst_gpio_num = EXAMPLE_PIN_NUM_TOUCH_RST,
        .int_gpio_num = EXAMPLE_PIN_NUM_TOUCH_INT,
        .levels = {
            .reset = 0,
            .interrupt = 0,
        },
        .flags = {
#if (AMOLED_Rotate == Rotate_90)
            .swap_xy = 1,
            .mirror_x = 0,
            .mirror_y = 1,
#else
            .swap_xy = 0,
            .mirror_x = 0,
            .mirror_y = 0,
#endif
        },
    };

    ESP_LOGI(TAG, "Initialize touch controller");
    ESP_ERROR_CHECK(esp_lcd_touch_new_i2c_ft5x06(tp_io_handle, &tp_cfg, &tp));
#endif
  ESP_LOGI(TAG, "Initialize LVGL library");
  lv_init();
  // alloc draw buffers used by LVGL
  // it's recommended to choose the size of the draw buffer(s) to be at least 1/10 screen sized
  lv_color_t *buf1 = (lv_color_t*)heap_caps_malloc(EXAMPLE_LCD_H_RES * EXAMPLE_LVGL_BUF_HEIGHT * sizeof(lv_color_t), MALLOC_CAP_DMA);
  assert(buf1);
  lv_color_t *buf2 = (lv_color_t*)heap_caps_malloc(EXAMPLE_LCD_H_RES * EXAMPLE_LVGL_BUF_HEIGHT * sizeof(lv_color_t), MALLOC_CAP_DMA);
  assert(buf2);
  // initialize LVGL draw buffers
  lv_disp_draw_buf_init(&disp_buf, buf1, buf2, EXAMPLE_LCD_H_RES * EXAMPLE_LVGL_BUF_HEIGHT);

  ESP_LOGI(TAG, "Register display driver to LVGL");
  lv_disp_drv_init(&disp_drv);
  disp_drv.hor_res = EXAMPLE_LCD_H_RES;
  disp_drv.ver_res = EXAMPLE_LCD_V_RES;
  disp_drv.flush_cb = example_lvgl_flush_cb;
  disp_drv.rounder_cb = example_lvgl_rounder_cb;
  disp_drv.drv_update_cb = example_lvgl_update_cb;
  disp_drv.draw_buf = &disp_buf;
  disp_drv.user_data = panel_handle;
  lv_disp_t *disp = lv_disp_drv_register(&disp_drv);

  ESP_LOGI(TAG, "Install LVGL tick timer");
  // Tick interface for LVGL (using esp_timer to generate 2ms periodic event)
  const esp_timer_create_args_t lvgl_tick_timer_args = {
      .callback = &example_increase_lvgl_tick,
      .name = "lvgl_tick"
  };
  esp_timer_handle_t lvgl_tick_timer = NULL;
  ESP_ERROR_CHECK(esp_timer_create(&lvgl_tick_timer_args, &lvgl_tick_timer));
  ESP_ERROR_CHECK(esp_timer_start_periodic(lvgl_tick_timer, EXAMPLE_LVGL_TICK_PERIOD_MS * 1000));
#if EXAMPLE_USE_TOUCH
    static lv_indev_drv_t indev_drv;    // Input device driver (Touch)
    lv_indev_drv_init(&indev_drv);
    indev_drv.type = LV_INDEV_TYPE_POINTER;
    indev_drv.disp = disp;
    indev_drv.read_cb = example_lvgl_touch_cb;
    indev_drv.user_data = tp;
    lv_indev_drv_register(&indev_drv);
#endif

  lvgl_mux = xSemaphoreCreateMutex();
  assert(lvgl_mux);
  xTaskCreate(example_lvgl_port_task, "LVGL", EXAMPLE_LVGL_TASK_STACK_SIZE, NULL, EXAMPLE_LVGL_TASK_PRIORITY, NULL);

  //Lock the mutex due to the LVGL APIs are not thread-safe
  if (example_lvgl_lock(-1))
  {
    ui_init();
    example_lvgl_unlock();

    Serial.begin(115200);                             // for USB debug
    Serial2.begin(115200, SERIAL_8N1, 18, 8);         // ESP32 <-UART-> Pi5 (GPIO18 = RX, GPIO8 = TX)
    Serial.println("UART2 init");

    esp_err_t ret = nvs_flash_init();

    if (ret == ESP_ERR_NVS_NO_FREE_PAGES || ret == ESP_ERR_NVS_NEW_VERSION_FOUND) {
        nvs_flash_erase();
        nvs_flash_init();
    }

    // Load calibration data
    load_lane_limit_from_nvs(&g_laneLimit);

  }
}


String uart_buf = "";
int g_setValL = 0;
int g_setValR = 0;


void loop()
{

  while (Serial2.available())
  {
    char c = Serial2.read();

    if (c == '\n')
    {
      Serial.println("[RX] " + uart_buf);

      if (uart_buf.startsWith("$HUD"))
      {
        float offset = 0, tSigST=0, dist = 0;

        if (sscanf(uart_buf.c_str(), "$HUD,%f,%f,%f", &offset, &tSigST, &dist) == 3)
        {
          HUD_run(offset, tSigST);
          dist_warn(dist);
        }
        else
        {
          Serial.println("[WARN] error");
        }
      }

      uart_buf = "";

    }
    else
    {
      uart_buf += c;
    }
  }

  delay(1);
}

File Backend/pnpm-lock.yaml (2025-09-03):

lockfileVersion: '9.0'

settings:
  autoInstallPeers: true
  excludeLinksFromLockfile: false

importers:

  .:
    dependencies:
      '@prisma/client':
        specifier: ^6.7.0
        version: 6.12.0(prisma@6.12.0)
      cors:
        specifier: ^2.8.5
        version: 2.8.5
      dotenv:
        specifier: ^16.5.0
        version: 16.6.1
      express:
        specifier: ^5.1.0
        version: 5.1.0
      http-status-codes:
        specifier: ^2.3.0
        version: 2.3.0
      https:
        specifier: ^1.0.0
        version: 1.0.0
      jsonwebtoken:
        specifier: ^9.0.2
        version: 9.0.2
      prisma:
        specifier: ^6.7.0
        version: 6.12.0
      swagger-autogen:
        specifier: ^2.23.7
        version: 2.23.7
      swagger-ui-express:
        specifier: ^5.0.1
        version: 5.0.1(express@5.1.0)
      ws:
        specifier: ^8.18.3
        version: 8.18.3
    devDependencies:
      nodemon:
        specifier: ^3.1.10
        version: 3.1.10

packages:

  '@prisma/client@6.12.0':
    resolution: {integrity: sha512-wn98bJ3Cj6edlF4jjpgXwbnQIo/fQLqqQHPk2POrZPxTlhY3+n90SSIF3LMRVa8VzRFC/Gec3YKJRxRu+AIGVA==}
    engines: {node: '>=18.18'}
    peerDependencies:
      prisma: '*'
      typescript: '>=5.1.0'
    peerDependenciesMeta:
      prisma:
        optional: true
      typescript:
        optional: true

  '@prisma/config@6.12.0':
    resolution: {integrity: sha512-HovZWzhWEMedHxmjefQBRZa40P81N7/+74khKFz9e1AFjakcIQdXgMWKgt20HaACzY+d1LRBC+L4tiz71t9fkg==}

  '@prisma/debug@6.12.0':
    resolution: {integrity: sha512-plbz6z72orcqr0eeio7zgUrZj5EudZUpAeWkFTA/DDdXEj28YHDXuiakvR6S7sD6tZi+jiwQEJAPeV6J6m/tEQ==}

  '@prisma/engines-version@6.12.0-15.8047c96bbd92db98a2abc7c9323ce77c02c89dbc':
    resolution: {integrity: sha512-70vhecxBJlRr06VfahDzk9ow4k1HIaSfVUT3X0/kZoHCMl9zbabut4gEXAyzJZxaCGi5igAA7SyyfBI//mmkbQ==}

  '@prisma/engines@6.12.0':
    resolution: {integrity: sha512-4BRZZUaAuB4p0XhTauxelvFs7IllhPmNLvmla0bO1nkECs8n/o1pUvAVbQ/VOrZR5DnF4HED0PrGai+rIOVePA==}

  '@prisma/fetch-engine@6.12.0':
    resolution: {integrity: sha512-EamoiwrK46rpWaEbLX9aqKDPOd8IyLnZAkiYXFNuq0YsU0Z8K09/rH8S7feOWAVJ3xzeSgcEJtBlVDrajM9Sag==}

  '@prisma/get-platform@6.12.0':
    resolution: {integrity: sha512-nRerTGhTlgyvcBlyWgt8OLNIV7QgJS2XYXMJD1hysorMCuLAjuDDuoxmVt7C2nLxbuxbWPp7OuFRHC23HqD9dA==}

  '@scarf/scarf@1.4.0':
    resolution: {integrity: sha512-xxeapPiUXdZAE3che6f3xogoJPeZgig6omHEy1rIY5WVsB3H2BHNnZH+gHG6x91SCWyQCzWGsuL2Hh3ClO5/qQ==}

  accepts@2.0.0:
    resolution: {integrity: sha512-5cvg6CtKwfgdmVqY1WIiXKc3Q1bkRqGLi+2W/6ao+6Y7gu/RCwRuAhGEzh5B4KlszSuTLgZYuqFqo5bImjNKng==}
    engines: {node: '>= 0.6'}

  acorn@7.4.1:
    resolution: {integrity: sha512-nQyp0o1/mNdbTO1PO6kHkwSrmgZ0MT/jCCpNiwbUjGoRN4dlBhqJtoQuCnEOKzgTVwg0ZWiCoQy6SxMebQVh8A==}
    engines: {node: '>=0.4.0'}
    hasBin: true

  anymatch@3.1.3:
    resolution: {integrity: sha512-KMReFUr0B4t+D+OBkjR3KYqvocp2XaSzO55UcB6mgQMd3KbcE+mWTyvVV7D/zsdEbNnV6acZUutkiHQXvTr1Rw==}
    engines: {node: '>= 8'}

  balanced-match@1.0.2:
    resolution: {integrity: sha512-3oSeUO0TMV67hN1AmbXsK4yaqU7tjiHlbxRDZOpH0KW9+CeX4bRAaX0Anxt0tx2MrpRpWwQaPwIlISEJhYU5Pw==}

  binary-extensions@2.3.0:
    resolution: {integrity: sha512-Ceh+7ox5qe7LJuLHoY0feh3pHuUDHAcRUeyL2VYghZwfpkNIy/+8Ocg0a3UuSoYzavmylwuLWQOf3hl0jjMMIw==}
    engines: {node: '>=8'}

  body-parser@2.2.0:
    resolution: {integrity: sha512-02qvAaxv8tp7fBa/mw1ga98OGm+eCbqzJOKoRt70sLmfEEi+jyBYVTDGfCL/k06/4EMk/z01gCe7HoCH/f2LTg==}
    engines: {node: '>=18'}

  brace-expansion@1.1.12:
    resolution: {integrity: sha512-9T9UjW3r0UW5c1Q7GTwllptXwhvYmEzFhzMfZ9H7FQWt+uZePjZPjBP/W1ZEyZ1twGWom5/56TF4lPcqjnDHcg==}

  braces@3.0.3:
    resolution: {integrity: sha512-yQbXgO/OSZVD2IsiLlro+7Hf6Q18EJrKSEsdoMzKePKXct3gvD8oLcOQdIzGupr5Fj+EDe8gO/lxc1BzfMpxvA==}
    engines: {node: '>=8'}

  buffer-equal-constant-time@1.0.1:
    resolution: {integrity: sha512-zRpUiDwd/xk6ADqPMATG8vc9VPrkck7T07OIx0gnjmJAnHnTVXNQG3vfvWNuiZIkwu9KrKdA1iJKfsfTVxE6NA==}

  bytes@3.1.2:
    resolution: {integrity: sha512-/Nf7TyzTx6S3yRJObOAV7956r8cr2+Oj8AC5dt8wSP3BQAoeX58NoHyCU8P8zGkNXStjTSi6fzO6F0pBdcYbEg==}
    engines: {node: '>= 0.8'}

  call-bind-apply-helpers@1.0.2:
    resolution: {integrity: sha512-Sp1ablJ0ivDkSzjcaJdxEunN5/XvksFJ2sMBFfq6x0ryhQV/2b/KwFe21cMpmHtPOSij8K99/wSfoEuTObmuMQ==}
    engines: {node: '>= 0.4'}

  call-bound@1.0.4:
    resolution: {integrity: sha512-+ys997U96po4Kx/ABpBCqhA9EuxJaQWDQg7295H4hBphv3IZg0boBKuwYpt4YXp6MZ5AmZQnU/tyMTlRpaSejg==}
    engines: {node: '>= 0.4'}

  chokidar@3.6.0:
    resolution: {integrity: sha512-7VT13fmjotKpGipCW9JEQAusEPE+Ei8nl6/g4FBAmIm0GOOLMua9NDDo/DWp0ZAxCr3cPq5ZpBqmPAQgDda2Pw==}
    engines: {node: '>= 8.10.0'}

  concat-map@0.0.1:
    resolution: {integrity: sha512-/Srv4dswyQNBfohGpz9o6Yb3Gz3SrUDqBH5rTuhGR7ahtlbYKnVxw2bCFMRljaA7EXHaXZ8wsHdodFvbkhKmqg==}
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

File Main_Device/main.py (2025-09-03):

from multiprocessing import Process, Queue, Manager
import threading
import time
import asyncio
import websockets
import ssl
import json
import ws_messages as socket

from LDS import Lds
from gaze import gaze
from VDP import GPIO
from VDP.GPS import VDP_GPS
from VDP.IMU import VDP_IMU
from lib import gData as g

# --------------------------------------------------------------------------------
#  Constants
# --------------------------------------------------------------------------------
DEIVCE_CODE = "adasdafagfas1_Ada_dasgafsadas"
URL = "wss://api.driving.p-e.kr/ws"

# -- Gaze/LDS Configs
GAZE_VIDEO_PATH = 0 #'./videos/4.mp4'
GAZE_HEF_PATH = './gaze/weight/gaze.hef'
GAZE_LABEL_PATH = './gaze/weight/coco.txt'

LDS_MODE = 1  # 0:jpg, 1:mp4, 2:usb cam
LDS_CAM_CH = 2
LDS_VIDEO_PATH = 2 #"./videos/2.mp4"
LDS_HEF_PATH = "./LDS/yolov7.hef"
LDS_LABEL_PATH = "./LDS/labals.txt"

# --------------------------------------------------------------------------------
#  State Management Class
# --------------------------------------------------------------------------------
class DeviceState:
    def __init__(self, device_code):
        self.device_code = device_code
        self.device_id = None
        self.device_status = 0  # 0: idle, 1: running, 2: stopping
        
        self.threading_running = True
        
        self.mileage = 0
        self.mileage_lock = threading.Lock()
        
        self.ws_lock = asyncio.Lock()

        # Task management for state polling
        self.check_state_task = None
        self.check_state_stop_event = None

    def set_mileage(self, mileage):
        with self.mileage_lock:
            self.mileage = mileage

    def get_mileage(self):
        with self.mileage_lock:
            return self.mileage

# --------------------------------------------------------------------------------
#  WebSocket Communication
# --------------------------------------------------------------------------------
async def init_device(device_state, websocket):
    msg_init = socket.get_init_message(device_state.device_code)
    response = await send_msg(websocket, msg_init, device_state)
    if response in ("RECONNECT", "TIMEOUT", None):
        # Retry once
        websocket = await connect_until_success(URL)
        response = await send_msg(websocket, msg_init, device_state)

    if response not in ("RECONNECT", "TIMEOUT", None):
        try:
            data = json.loads(response)
            device_state.device_id = data["data"]["deviceId"]
            print("DEVICE_ID", device_state.device_id)
        except (json.JSONDecodeError, KeyError) as e:
            print(f"[ERROR] Failed to parse device ID from response: {response}, error: {e}")
            return None
    return websocket

async def connect_until_success(uri):
    ssl_context = ssl._create_unverified_context()
    while True:
        try:
            print("[INFO] Trying to connect to WebSocket...")
            websocket = await websockets.connect(uri, ssl=ssl_context)
            print("[SUCCESS] Connected to WebSocket server.")
            return websocket
        except Exception as e:
            print(f"[RETRY] Connection failed: {e}")
            await asyncio.sleep(2)

async def send_msg(websocket, msg, device_state, timeout=3.0):
    try:
        async with device_state.ws_lock:
            await websocket.send(json.dumps(msg))
            print(f"[INFO] Message sent: {msg}")

        response = await asyncio.wait_for(websocket.recv(), timeout=timeout)
        print(f"[WS] Response received: {response}")
        return response
    except asyncio.TimeoutError:
        print("[ERROR] WebSocket recv timeout.")
        return "TIMEOUT"
    except websockets.ConnectionClosed:
        print("[ERROR] WebSocket connection closed.")
        return "RECONNECT"
    except Exception as e:
        print(f"[ERROR] Communication failed: {e}")
        return None

async def send_result(websocket, msg_gaze, msg_lds, device_state):
    final_msg = socket.get_stop_message(device_state.device_id, msg_gaze, msg_lds)
    print(final_msg)
    
    result = await send_msg(websocket, final_msg, device_state)
    if result in ("RECONNECT", "TIMEOUT", None):
        # If sending fails, reconnect and try once more.
        websocket = await connect_until_success(URL)
        await send_msg(websocket, final_msg, device_state)

# --------------------------------------------------------------------------------
#  Device State Polling
# --------------------------------------------------------------------------------
async def thread_check_state(websocket, device_state):
    while not device_state.check_state_stop_event.is_set():
        mileage = device_state.get_mileage()
        msg = socket.get_status_message(device_state.device_id, mileage)

        receive = await send_msg(websocket, msg, device_state)

        if receive in ("RECONNECT", "TIMEOUT", None):
            websocket = await connect_until_success(URL)
            await asyncio.sleep(1)
            continue

        try:
            status_data = json.loads(receive)
            status = status_data.get("data", {}).get("status")
        except (json.JSONDecodeError, AttributeError):
            print(f"[WS] Invalid JSON while parsing status: {receive}")
            status = None

        if status is None:
            print(f"[WARN] status missing in response: {receive}")
        else:
            device_state.device_status = status
            update_led_by_status(status)
        
        await asyncio.sleep(1)

def update_led_by_status(status):
    led_states = {
        0: (1, 0, 0),  # RED
        1: (0, 1, 0),  # YELLOW
        2: (0, 0, 1)   # BLUE
    }
    r, y, b = led_states.get(status, (1, 0, 0)) # Default to RED
    print(f"DEVICE_STATE : {status}")
    GPIO.toggle_LED(GPIO.RED_LED, r)
    GPIO.toggle_LED(GPIO.YELLOW_LED, y)
    GPIO.toggle_LED(GPIO.BLUE_LED, b)

def start_check_state_task(websocket, device_state):
    if device_state.check_state_task is None or device_state.check_state_task.done():
        device_state.check_state_stop_event = asyncio.Event()
        device_state.check_state_task = asyncio.create_task(thread_check_state(websocket, device_state))
        print("[INFO] check_state Thread begin")

async def stop_check_state_task(device_state):
    if device_state.check_state_stop_event:
        device_state.check_state_stop_event.set()
    if device_state.check_state_task:
        try:
            await asyncio.wait_for(device_state.check_state_task, timeout=2.0)
        except asyncio.TimeoutError:
            print("[WARN] check_state task did not exit in time.")
        device_state.check_state_task = None
    print("[INFO] check_state Thread end")
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
